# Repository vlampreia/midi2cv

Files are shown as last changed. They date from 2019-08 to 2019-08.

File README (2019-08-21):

Another MIDI to CV project!
================================================================================

This project arose out of the desire to control antiquated drum machines which
respond to analogue pulses with MIDI enabled devices. MIDI to CV solutions exist
in abundance, nonetheless I saw this as an opportunity to involve myself in more
embedded software development and as an introduction to hardware development.

This project does not consider modular synthesiser CV in any way whatsoever. The
end devices this converter is targeted to drive respond to simple voltage-level
triggers, and so it lacks output voltage scaling and MIDI processing for
anything other than channel, note, and velocity parameters at this time.

SYSTEM OVERVIEW AND REQUIREMENTS
--------------------------------------------------------------------------------

At a top level, the system processes MIDI and outputs up to 8 analogue pulses
simultaneously. It must be capable of mapping channel, note, and velocity data
from MIDI packets to their respective analogue values and CV DACs as programmed
by the user, in real time and with imperceptible jitter.

MIDI channel and note to CV channel mappings are user configurable using the
front panel, which provides a 3 character display and a set of momentary
switches. User settings are stored in the MCU flash memory and persist after a
loss of power.

INTERFACE
--------------------------------------------------------------------------------

The system is abstracted into programmable CV channels. Each CV channel has a
MIDI channel and note assigned to it. Channels may also be configured to respond
to all MIDI channels and or all note values.

The user interface consists of a display showing the current mode and value, and
three buttons, one to cycle mode (CV channel, MIDI channel, and MIDI note, in
that order), and two to increment and decrement the value. The omni value can be
selected by holding down both value buttons.

FIRMWARE
--------------------------------------------------------------------------------

The MCU firmware is written in C and is listed under ./firmware.

This is currently a work in progress.

A makefile is present to facilitate building and flashing the firmware. It
targets the ATMega328P-PU using a USBASP programmer.

HARDWARE
--------------------------------------------------------------------------------

The hardware platform is designed using KiCAD and is listed under ./hardware.

This is currently a work in progress. A full BOM will be rendered once the
hardware has been finalised.

The platform consists of two boards interconnected via standard pin headers:
- The main board hosting the MCU, power and MIDI input stages, as well as the CV
  output stage.
- The HUI board hosting the display and navigation buttons.

The MCU is an ATMega328, selected for it's simplicity and active community base,
it is a fairly capable package boasting a 20MHz clock, 2KB RAM, USART and a SPI.
The 328 lacks any digital to analogue conversion, for this the 8bit MCP4802 was
selected. Each IC packages 2 DACs, addressable via SPI by the MCU.

The MIDI input stage follows the standards set out by the MIDI spec. A H11L1 was
selected for the optoisolator, which is identical to the PC900 suggested in the
spec.

Control voltage outputs are buffered internally by the DACs. Output voltage can
vary from 0v to about 4v on max gain.

Supply input is regulated and can scale from 8v to 35v.

KNOWN LIMITATIONS AND FUTURE IMPROVEMENTS
--------------------------------------------------------------------------------

- The output voltage scale is an unknown and can change from target device to
  device. The hardware currently lacks support for programmable output voltage
  scaling.

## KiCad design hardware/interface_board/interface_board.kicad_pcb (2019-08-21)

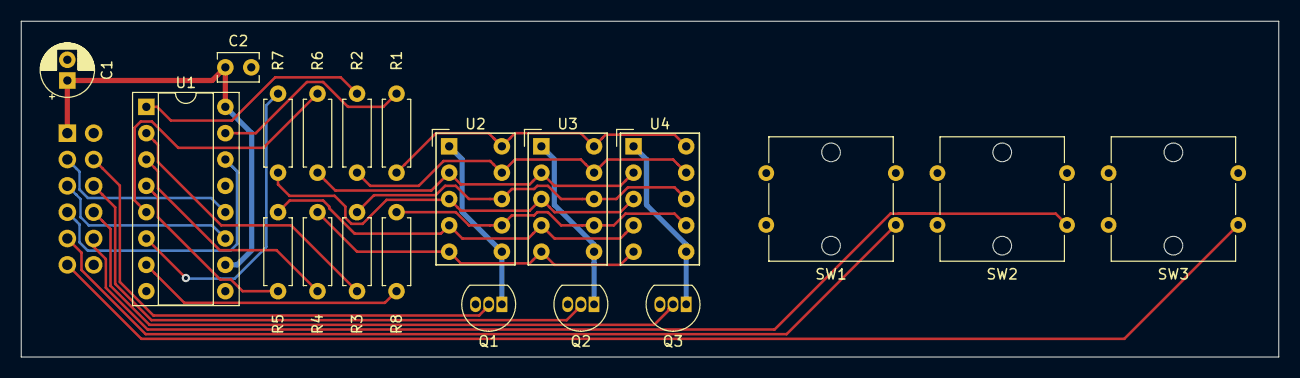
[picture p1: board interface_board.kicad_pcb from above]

Board: 2 copper layers, 121.3 x 32.4 mm, 21 parts (1 on the bottom side), 30 nets.

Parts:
C1: 10uF; CP_Radial_D5.0mm_P2.00mm
C2: 0.1uF; C_Disc_D3.8mm_W2.6mm_P2.50mm
J1: Conn_02x06_Odd_Even; PinSocket_2x06_P2.54mm_Vertical
Q1, Q2, Q3: BC548; TO-92_Inline
R1, R2, R3, R4, R5, R6, R7, R8: R_Small_US; R_Axial_DIN0207_L6.3mm_D2.5mm_P7.62mm_Horizontal
SW1, SW2, SW3: SW_SPST; B3W-4050
U1: 74HC595; DIP-16_W7.62mm_Socket
U2, U3, U4: SC36-11SEKWA; HDSP-7401

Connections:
+5V: C1.1, C2.1, J1.1, U1.10, U1.16
/BTN_1: J1.9, SW1.1
/BTN_2: J1.10, SW2.1
/BTN_3: J1.11, SW3.1
/DISP_1_CS: J1.4, Q1.2
/DISP_2_CS: J1.6, Q2.2
/DISP_3_CS: J1.8, Q3.2
/LATCH: J1.3, U1.12
/SCLK: J1.5, U1.11
/SI: J1.7, U1.14
GND: C1.2, C2.2, J1.2, Q1.3, Q2.3, Q3.3, SW1.2, SW2.2, SW3.2, U1.8, U1.13
unnamed: Q1.1, U2.1, U2.6
unnamed: Q2.1, U3.1, U3.6
unnamed: Q3.1, U4.1, U4.6
unnamed: R1.1, U2.10, U3.10, U4.10
unnamed: R1.2, U1.15
unnamed: R2.1, U2.9, U3.9, U4.9
unnamed: R2.2, U1.1
unnamed: R3.1, U2.8, U3.8, U4.8
unnamed: R3.2, U1.2
unnamed: R4.1, U2.5, U3.5, U4.5
unnamed: R4.2, U1.3
unnamed: R5.1, U2.4, U3.4, U4.4
unnamed: R5.2, U1.4
unnamed: R6.1, U2.2, U3.2, U4.2
unnamed: R6.2, U1.5
unnamed: R7.1, U2.3, U3.3, U4.3
unnamed: R7.2, U1.6
unnamed: R8.1, U2.7, U3.7, U4.7
unnamed: R8.2, U1.7

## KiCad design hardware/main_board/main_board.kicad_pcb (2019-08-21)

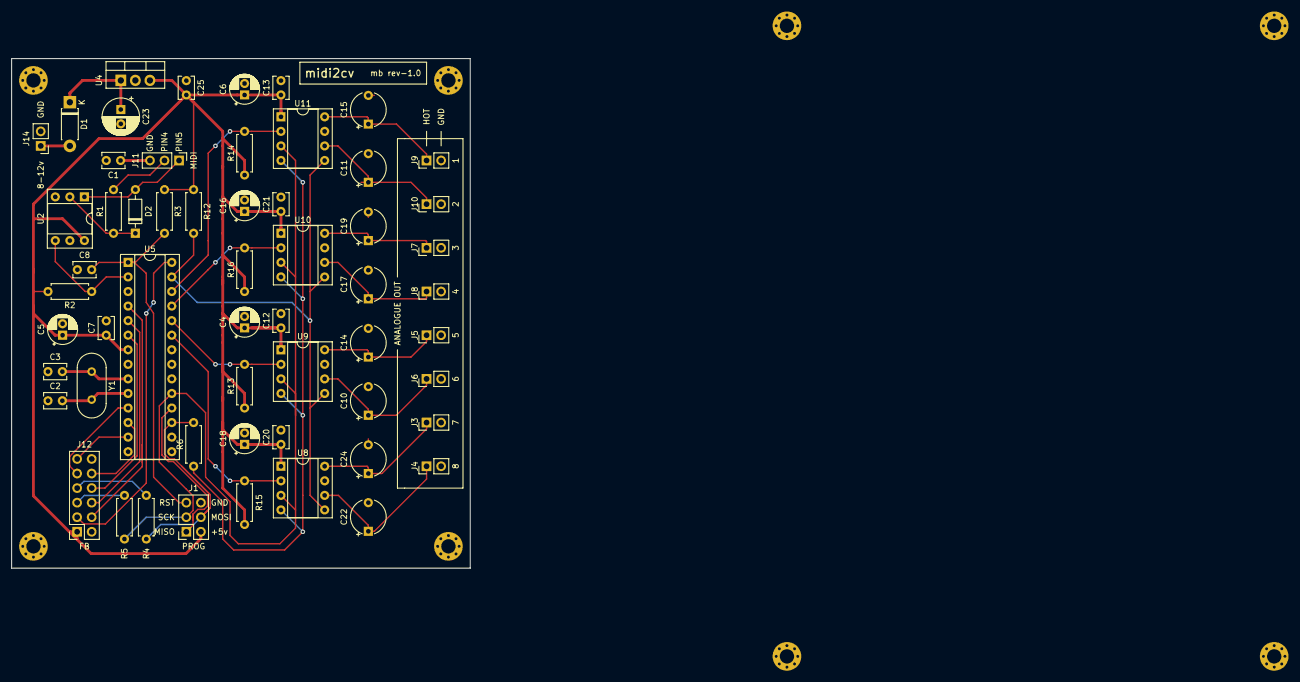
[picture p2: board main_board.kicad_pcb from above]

Board: 2 copper layers, 80.0 x 88.9 mm, 57 parts (0 on the bottom side), 38 nets.

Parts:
C1, C7, C12, C13, C20, C21, C25: 0.1uF; C_Disc_D3.8mm_W2.6mm_P2.50mm
C2, C3: 22pF; C_Disc_D3.8mm_W2.6mm_P2.50mm
C4, C5, C6, C16, C18: 10uF; CP_Radial_D5.0mm_P2.00mm
C8: 100nF; C_Disc_D3.8mm_W2.6mm_P2.50mm
C10, C11, C14, C15, C17, C19, C22, C24: 1uF; CP_Radial_Tantal_D6.0mm_P5.00mm
C23: 0.33uF; CP_Radial_D6.3mm_P2.50mm
D1: D_ALT; D_DO-41_SOD81_P7.62mm_Horizontal
D2: 1N914; D_DO-35_SOD27_P7.62mm_Horizontal
J1: Conn_02x03_Odd_Even; PinSocket_2x03_P2.54mm_Vertical
J3, J4, J5, J6, J7, J8, J9, J10, J14: Conn_01x02; PinHeader_1x02_P2.54mm_Vertical
J11: Conn_01x02; PinHeader_1x03_P2.54mm_Vertical
J12: Conn_02x03_Odd_Even; PinSocket_2x06_P2.54mm_Vertical
R1: 220; R_Axial_DIN0207_L6.3mm_D2.5mm_P7.62mm_Horizontal
R2: 270; R_Axial_DIN0207_L6.3mm_D2.5mm_P7.62mm_Horizontal
R3, R4, R5, R6, R12, R13, R14, R15, R16: 4k7; R_Axial_DIN0207_L6.3mm_D2.5mm_P7.62mm_Horizontal
U2: H11L1; DIP-6_W7.62mm_Socket
U4: L7805; TO-220-3_Vertical
U5: ATmega328P-PU; DIP-28_W7.62mm_Socket
U8, U9, U10, U11: MCP4802; DIP-8_W7.62mm_Socket
Y1: 20MHz; Crystal_HC49-U_Vertical

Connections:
+5V: C4.1, C5.1, C6.1, C7.1, C12.1, C13.1, C16.1, C18.1, C20.1, C21.1, C25.1, J1.2, J12.1, R2.2, R3.1, R12.1, R13.1, R14.1, R15.1, R16.1, U2.6, U4.3, U5.7, U8.1, U9.1, U10.1, U11.1
/BTN_1: J12.9, U5.11
/BTN_2: J12.10, U5.12
/BTN_3: J12.11, U5.13
/CS_1: R15.2, U5.23, U8.2
/CS_2: R13.2, U5.24, U9.2
/CS_3: R16.2, U5.25, U10.2
/CS_4: R14.2, U5.26, U11.2
/DISP_1_CS: J12.4, U5.4
/DISP_2_CS: J12.6, U5.5
/DISP_3_CS: J12.8, U5.6
/LDAC: R12.2, U5.27, U8.5, U9.5, U10.5, U11.5
/LDISP: J12.3, U5.28
/MIDI_4: J11.2, R1.2
/MIDI_5: D2.2, J11.1, U2.1
/MIDI_GND: C1.1, J11.3
/MIDI_IN: R2.1, U2.4, U5.2
/MISO: J1.1, U5.18
/MOSI: J1.4, R5.2, R6.2, U5.17
/RES: C8.2, J1.5, R3.2, U5.1
/SCK: J1.3, R4.2, U5.19, U8.3, U9.3, U10.3, U11.3
/dac_section/OUT_1: C24.1, J3.1, U8.8
/dac_section/OUT_2: C22.1, J4.1, U8.6
/dac_section/OUT_3: C14.1, J5.1, U9.8
/dac_section/OUT_4: C10.1, J6.1, U9.6
/dac_section/OUT_5: C19.1, J7.1, U10.8
/dac_section/OUT_6: C17.1, J8.1, U10.6
/dac_section/OUT_7: C15.1, J9.1, U11.8
/dac_section/OUT_8: C11.1, J10.1, U11.6
/dac_section/SI: R6.1, U8.4, U9.4, U10.4, U11.4
GND: C1.2, C2.1, C3.1, C4.2, C5.2, C6.2, C7.2, C8.1, C10.2, C11.2, C12.2, C13.2, C14.2, C15.2, C16.2, C17.2, C18.2, C19.2, C20.2, C21.2, C22.2, C23.2, C24.2, C25.2, J1.6, J3.2, J4.2, J5.2, J6.2, J7.2, J8.2, J9.2, J10.2, J12.2, J14.2, U2.5, U4.2, U5.8, U5.22, U8.7, U9.7, U10.7, U11.7
unnamed: C2.2, U5.10, Y1.2
unnamed: C3.2, U5.9, Y1.1
unnamed: C23.1, D1.1, U4.1
unnamed: D1.2, J14.1
unnamed: D2.1, R1.1, U2.2
unnamed: J12.5, R4.1
unnamed: J12.7, R5.1

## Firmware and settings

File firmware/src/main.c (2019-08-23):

#ifndef F_CPU
#define F_CPU 20000000UL
#endif

#include <avr/io.h>
#include <avr/interrupt.h>
#include <avr/wdt.h>
#include <avr/eeprom.h>
#include <stddef.h>

#include "cbuff.h"
#include "mcp4802.h"
#include "cvchan.h"
#include "midi.h"
#include "segdisp.h"
#include "btn.h"
#include "view.h"
#include "view_data.h"
#include "view_channel.h"
#include "view_midi_channel.h"
#include "view_midi_note.h"
#include "helpers.h"

/* -------------------------------------------------------------------------- */

#define BUFFER_SIZE 32
#define MIDI_BUFFER_SIZE 64

#define DAC_LDAC_PORT PORTC
#define DAC_LDAC_PIN PINC3

#define CHANNEL_COUNT 8
#define DAC_COUNT (CHANNEL_COUNT > 1 ? CHANNEL_COUNT / 2 : 1) //mcp4802 holds two dacs each

#define BUTTON_COUNT 3

/* -------------------------------------------------------------------------- */

enum display_mode {
    disp_mode_channel,
    disp_mode_midi,
    disp_mode_note,
    disp_mode_debug
};

/* globals */
struct MCP4802  dacs[DAC_COUNT];
uint8_t         cbuff_buffers[CHANNEL_COUNT * BUFFER_SIZE];
struct cbuff    buffers[CHANNEL_COUNT];
struct cvchan   channels[CHANNEL_COUNT];
struct cbuff    midi_buffer = {0};
struct segdisp  disp = {0};
struct btn      buttons[BUTTON_COUNT];

static volatile uint8_t sig_proc_ana_buff = 0;
static volatile uint8_t update_display_trig = 0;
static volatile uint8_t update_midi_trig = 0;
static volatile uint8_t sample_input_trig = 0;
static volatile uint8_t process_input_trig  = 0;

struct view view_channel;
struct view view_midi_channel;
struct view view_midi_note;

enum display_mode   disp_mode;
uint8_t             disp_sent;
uint8_t             disp_dbg = 0;

/* non-volatile memory */
struct nv_channel {
    uint8_t midi_channel;
    uint8_t note;
};
static struct nv_channel EEMEM nv_channels[CHANNEL_COUNT];

/* functions */
static void spi_init (void);
static void spi_send (uint8_t data);
static void spi_send_uint16_t (uint16_t data);
static void buffer_advance (void);
static void init_timers (void);
static void setup_buffers (void);
static void setup_usart (void);
static void init_channels (void);
static void process_midi (uint8_t byte);
static void write_pulse (uint8_t peak_value, struct cbuff *b);
static void update_display (void);
static void store_settings (void);
static void load_settings (void);
static void config_gpio (void);
static uint8_t handle_ui_input (void);
static void setup_buttons(void);
static void update_inputs(void);
static void setup_display (void);
static void init_views (void);

/* -------------------------------------------------------------------------- */

void config_gpio (void) {
    DDRC = 0xFF;
    PORTC = 0x00;
    DDRD = (1 << DDD2) | (1 << DDD3) | (1 << DDD4) | (0 << DDD5) | (0 << DDD6) | (0 << DDD7);
    DDRB = (1 << DDB0) | (1 << DDB1) | (1 << DDB2);
    BIT_CLEAR(PORTC, PINC5);
    BIT_CLEAR(PORTC, PINC4);

    // internal inputs on 5,6,7 btn
    BIT_SET(PORTD, PIND5);
    BIT_SET(PORTD, PIND6);
    BIT_SET(PORTD, PIND7);
}

void init_channels (void) {
    for (size_t i=0; i<CHANNEL_COUNT; ++i) {
        MCP4802_init(&dacs[i/2], &DAC_LDAC_PORT, DAC_LDAC_PIN, &PORTC, PINC0);
        cbuff_init(&buffers[i], cbuff_buffers + i*BUFFER_SIZE, BUFFER_SIZE);
        cvchan_init(&channels[i], &buffers[i], &dacs[i/2], i % 2, 0, 0);
    }
}

void setup_usart (void) {
    /* set up usart for MIDI */
    /* frame format is ... */
    // baud rate
    uint16_t br = F_CPU / 16 / 31250 - 1;
    UBRR0H = (br >> 8);
    UBRR0L = (br & 0xFF);
    // frame format: 8 bit, 1 stop bit, 1 start bit
    UCSR0C = (1 << UCSZ01) | (1 << UCSZ00);
    // enable rx, rx isr
    UCSR0B = (1 << RXEN0) | (1 << RXCIE0);
}

void buffer_advance (void) {
    uint8_t latch_pins = 0;

    for (int i=0; i<CHANNEL_COUNT; ++i) {
        if (cvchan_proc_buffer(&channels[i], &spi_send_uint16_t)) continue;
        latch_pins |= channels[i].dac->ldac_pin;
    }

    if (latch_pins) {
        MCP4802_latch_direct(DAC_LDAC_PORT, latch_pins);
    }
}

void spi_init (void) {
    // MOSI, SCK output, SS master
    PORTC |= (1 << PINB2);
    DDRB = (1 << DDB5) | (1 << DDB3) | (1 << DDB2);

    // Enable SPI, Master, clock rate fck/16
    // default write MSB-first
    SPCR = (1 << SPE) | (1 << MSTR) | (1 << SPR0) | (1 << SPR1);
}

void spi_send (uint8_t data) {
    SPDR = data;

    /* wait for spi to be free */
    while (!(SPSR & (1 << SPIF)) && (SPCR & (1 << MSTR))) {}

    if (!(SPCR & (1 << MSTR))) {
        // DDRB |= (1 << DDB2);
        SPCR |= (1 << MSTR);
    }

    // force clear
    SPSR;
}

void spi_send_uint16_t (uint16_t data) {
    spi_send((data >> 8));
    spi_send(data & 0x00FF);
}

void init_timers (void) {
    /**
     * timerFreq = Fclk_io / (2 * N * (1 + OCRnA))
     * max timerFreq = Fclk_io / 2 when OCRnA == 0
     * N == selected prescalar factor
     *
     * CS12 CS11 CS10 Desc
     *    0    0    0 no clk src
     *    0    0    1 clk_io/1    prescaling
     *    0    1    0 clk_io/8    prescaling
     *    0    1    1 clk_io/64   prescaling
     *    1    0    0 clk_io/256  prescaling
     *    1    0    1 clk_io/1024 prescaling
     *
     * 1ms = 1000hz = 20Mhz / (2*8*2500)
     */

    TCCR0A = (1 << WGM01); // set CTC mode, TOP = OCR0A
    TCCR0B = (1 << CS02) | (1 << CS00); // clk/1024
    OCR0A = 33;
    TIMSK0 = (1 << OCIE0A); // enable CTC compare A

}

/* ISR */

ISR (USART_RX_vect) {
    uint8_t data = UDR0;
    if (data >= 0xF0) {
        return; // filter non common msgs
    }
    cbuff_write(&midi_buffer, data);
}

ISR (TIMER0_COMPA_vect) {
    sig_proc_ana_buff++;
    update_display_trig++;
    update_midi_trig++;
    sample_input_trig++;
    process_input_trig++;
}

/* /ISR */

void setup_buffers (void) {
    static uint8_t midi_buffer_d[MIDI_BUFFER_SIZE];
    cbuff_init(&midi_buffer, midi_buffer_d, MIDI_BUFFER_SIZE);
}

void write_pulse (uint8_t peak_value, struct cbuff *b) {
    cbuff_write(b, peak_value);
}

void process_midi (uint8_t byte) {
    static struct midi_event event = { 0 };

    midi_parse_next(&event, byte);
    if (!event.has_d2) return;

    uint8_t value = 0;
    disp_sent = 0;

    for (int i=0; i<CHANNEL_COUNT; ++i) {
        if (cvchan_proc_midi(&channels[i], &event, &value)) {
            continue;
        }

        write_pulse(value, channels[i].buffer);
        if (value) disp_sent = 1;
    }

    update_display();
}

void update_display (void) {
    static char text[] = "---";

    switch (disp_mode) {
        case disp_mode_channel:
            view_update_display(&view_channel);
            break;

        case disp_mode_midi:
            view_update_display(&view_midi_channel);
            break;

        case disp_mode_note:
            view_update_display(&view_midi_note);
            break;

        case disp_mode_debug: {
            text[0] = ((disp_dbg / 100) % 10) + 48;
            text[1] = ((disp_dbg / 10) % 10) + 48;
            text[2] =  (disp_dbg % 10) + 48;
            segdisp_set_value(&disp, text, 3);

            break;
        }
    }

    if (disp_sent) segdisp_overlay_value(&disp, ".  ", 3);
}

uint8_t handle_ui_input (void) {
    static size_t disp_mode_idx = 0;
    static enum display_mode mode_order[] = {
        disp_mode_channel,
        disp_mode_midi,
        disp_mode_note,
    };

    if (buttons[0].high) {
        disp_mode = mode_order[(disp_mode_idx++) % 3];
        return 1;
    }

    switch (disp_mode) {
        case disp_mode_channel:
            return view_update_input(&view_channel);

        case disp_mode_midi:
            return view_update_input(&view_midi_channel);

        case disp_mode_note:
            return view_update_input(&view_midi_note);

        case disp_mode_debug:
            if (buttons[0].high) {
                disp_mode = mode_order[0];
                return 1;
            }
            if (buttons[1].high) {
                disp_dbg--;
                return 1;
            }
            if (buttons[2].high) {
                disp_dbg++;
                return 1;
            }

            return 0;

        default:
            return 0;
    }
}

//TODO: reenable wdt for eeprom write protection
uint8_t mcusr_mirror __attribute__ ((section (".noinit")));

void get_mcusr (void) \
    __attribute__((naked)) \
    __attribute__((section(".init3")));
void get_mcusr (void) {
    mcusr_mirror = MCUSR;
    MCUSR = 0;
    wdt_disable();
}

void load_settings (void) {
    struct nv_channel settings[CHANNEL_COUNT];
    eeprom_read_block(&settings, &nv_channels, sizeof(struct nv_channel) * CHANNEL_COUNT);

    for (size_t i=0; i<CHANNEL_COUNT; ++i) {
        channels[i].midi_channel = settings[i].midi_channel;
        channels[i].note = settings[i].note;
    }
}

void store_settings (void) {
    struct nv_channel settings[CHANNEL_COUNT];

    for (size_t i=0; i<CHANNEL_COUNT; ++i) {
        settings[i].midi_channel = channels[i].midi_channel;
        settings[i].note = channels[i].note;
    }

    eeprom_update_block(&settings, &nv_channels, sizeof(struct nv_channel) * CHANNEL_COUNT);
}

static void setup_buttons(void) {
    btn_init(&buttons[0], &PIND, PIND5);
    btn_init(&buttons[1], &PIND, PIND6);
    btn_init(&buttons[2], &PIND, PIND7);
}

static void update_inputs(void) {
    for (size_t i=0; i<BUTTON_COUNT; ++i) {
        if (btn_update_state(&buttons[i])) {
            process_input_trig = 100;
        }
    }
}

static void setup_display (void) {
    // TODO: refactor to module init func
    static uint8_t pins[] = { PIND2, PIND3, PIND4 };
    static uint8_t values[3];

    disp.displays = 3;
    disp.select_pins = pins;
    disp.current_display = 0;
    disp.values = values;
    disp.select_port = &PORTD;
    disp.latch_port = &PORTC;
    disp.latch_pin=PINC5;
}

static void init_views (void) {
    static struct view_data vd;
    vd.selected_ch = 0;
    vd.disp = &disp;
    vd.channels = channels;
    vd.buttons = buttons;
    vd.channel_count = CHANNEL_COUNT;

    view_channel_init(&view_channel, &vd);
    view_midi_channel_init(&view_midi_channel, &vd);
    view_midi_note_init(&view_midi_note, &vd);
}

/* -------------------------------------------------------------------------- */

int main (void) {
    cli();
    config_gpio();
    init_channels();
    setup_buffers();
    setup_buttons();
    init_timers();
    setup_usart();
    spi_init();
    sei();

    init_views();

    // shutdown dacs until first used
    for (size_t i=0; i<DAC_COUNT; ++i) {
        MCP4802_disable_dac_spi(&dacs[i], 0, &spi_send_uint16_t);
        MCP4802_disable_dac_spi(&dacs[i], 1, &spi_send_uint16_t);
    }

    load_settings();
    setup_display();

    // initialise ui
    disp_mode = disp_mode_debug;
    update_display();

    uint8_t user_change = 0;

    while (1) {
        sei(); // SREG:I does not always reset to 1. This should be investigated
        // uint8_t s = BIT_CHECK(SREG, 7); // check interrupt flag

        // read midi buffer
        if (update_midi_trig >= 1) {
            update_midi_trig = 0;

            if (!cbuff_empty(&midi_buffer)) {
                uint8_t d = cbuff_read(&midi_buffer);
                process_midi(d);
            }
        }

        // write analogue out
        if (sig_proc_ana_buff >= 2) {
            sig_proc_ana_buff = 0;

            buffer_advance();
        }

        // refresh display
        if (update_display_trig >= 1) {
            update_display_trig = 0;

            segdisp_advance(&disp, &spi_send);
        }

        // debounce ui input
        if (sample_input_trig >= 10) {
            sample_input_trig = 0;

            update_inputs();
        }

        // process user input
        if (process_input_trig >= 100) {
            process_input_trig = 0;

            if (!buttons[0].high && !buttons[1].high && !buttons[2].high) {
                if (user_change && eeprom_is_ready()) {
                    store_settings();
                    user_change = 0;
                }

                continue;
            }

            user_change = handle_ui_input();
            update_display();
        }
    }
}

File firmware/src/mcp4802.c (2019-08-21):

#include "mcp4802.h"
#include "helpers.h"

void MCP4802_init (
    struct MCP4802 *d,
    volatile uint8_t *ldac_port,
    uint8_t ldac_pin,
    volatile uint8_t *cs_port,
    uint8_t cs_pin
) {
    d->ldac_port = ldac_port;
    d->ldac_pin = ldac_pin;
    d->cs_port = cs_port;
    d->cs_pin = cs_pin;
}

void MCP4802_latch (struct MCP4802 *d) {
    BIT_CLEAR(*(d->ldac_port), d->ldac_pin);
    BIT_SET(*(d->ldac_port), d->ldac_pin);
}

void MCP4802_latch_direct (volatile uint8_t port, uint8_t pins) {
    BIT_CLEAR(port, pins);
    BIT_SET(port, pins);
}

void MCP4802_send_spi (
    struct MCP4802 *d,
    int dac,
    uint8_t value,
    void (*spi_f)(uint16_t data)
) {
    uint16_t cmd = (1 << MCP4802_P_SHDN) |
        (1 << MCP4802_P_GA) |
        (dac << MCP4802_P_DAC) |
        (value << 4);

    MCP4802_send_raw_spi(d, cmd, spi_f);
}

void MCP4802_send_raw_spi (
    struct MCP4802 *d,
    uint16_t cmd,
    void (*spi_f)(uint16_t data)
) {
    BIT_CLEAR(*(d->cs_port), d->cs_pin);
    (*spi_f)(cmd);
    BIT_SET(*(d->cs_port), d->cs_pin);
}

void MCP4802_disable_dac_spi (
    struct MCP4802 *d,
    int dac,
    void (*spi_f)(uint16_t data)
) {
    uint16_t cmd = (dac << MCP4802_P_DAC);
    MCP4802_send_raw_spi(d, cmd, spi_f);
}

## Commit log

2019-08-21 firmware and hardware
    [dac_section.sch, interface_board.kicad_pcb, interface_board.sch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]
2019-08-21 HW: rename supply input diode value
    [dac_section.sch, main_board.sch]
2019-08-22 fw: refactor button debounce logic
